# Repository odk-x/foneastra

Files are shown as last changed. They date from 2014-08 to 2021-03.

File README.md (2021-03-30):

# foneastra

This project is __*actively maintained*__

It defines the Foneastra controller board and software for communicating with it.

The developer [wiki](https://github.com/odk-x/tool-suite-X/wiki) (including release notes) and [issues tracker](https://github.com/odk-x/tool-suite-X/issues) are located under the [**ODK-X Tool Suite**](https://github.com/odk-x) project.

## How to contribute
If you’re new to ODK-X you can check out the documentation:
- [https://docs.odk-x.org](https://docs.odk-x.org)

Once you’re up and running, you can choose an issue to start working on from here: 
- [https://github.com/odk-x/tool-suite-X/issues](https://github.com/odk-x/tool-suite-X/issues)

Issues tagged as [good first issue](https://github.com/odk-x/tool-suite-X/issues?q=is%3Aissue+is%3Aopen+label%3A%22good+first+issue%22) should be a good place to start.

Pull requests are welcome, though please submit them against the development branch. We prefer verbose descriptions of the change you are submitting. If you are fixing a bug please provide steps to reproduce it or a link to a an issue that provides that information. If you are submitting a new feature please provide a description of the need or a link to a forum discussion about it. 

## Links for users
This document is aimed at helping developers and technical contributors. For information on how to get started as a user of ODK-X, see our [online documentation](https://docs.odk-x.org), or to learn more about the Open Data Kit project, visit [https://odk-x.org](https://odk-x.org).

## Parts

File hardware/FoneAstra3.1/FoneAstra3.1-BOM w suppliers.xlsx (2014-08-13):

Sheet: Sheet2
Part | Value | Device | Package | Description | Digikey/SFE Part | Additional notes
$$U3 | BT_RESET | TESTPOINT | TESTPOINT
$$U4 | PIO6 | TESTPOINT | TESTPOINT
$$U5 | PIO7 | TESTPOINT | TESTPOINT
$$U6 | GND | TESTPOINT | TESTPOINT
$$U9 | PIO4 | TESTPOINT | TESTPOINT
$$U10 | PIO3 | TESTPOINT | TESTPOINT
$$U11 | PIO5 | TESTPOINT | TESTPOINT
$$U15 | FT/OUT | TESTPOINT | TESTPOINT
$$U16 | GND | TESTPOINT | TESTPOINT
BAT1 | 3V | BATTERY | BATTCON_12MM_CURVED | Battery Holders | SFE: http://www.sparkfun.com/products/10592
BT_PWR | BT_PWR | TESTPOINT | TESTPOINT
C1 | 0.1uF | CAP0402-CAP | 0402-CAP | Capacitor | 445-3445-1-ND
C2 | 0.1uF | CAP0402-CAP | 0402-CAP | Capacitor | 445-3445-1-ND
C3 | 0.1uF | CAP0402-CAP | 0402-CAP | Capacitor | 445-3445-1-ND
C4 | 0.1uF | CAP0402-CAP | 0402-CAP | Capacitor | 445-3445-1-ND
C5 | 0.1uF | CAP0402-CAP | 0402-CAP | Capacitor | 445-3445-1-ND
C6 | 0.1uF | CAP0402-CAP | 0402-CAP | Capacitor | 445-3445-1-ND
C7 | 18pF | CAP0402-CAP | 0402-CAP | Capacitor | 445-1238-1-ND
C8 | 18pF | CAP0402-CAP | 0402-CAP | Capacitor | 445-1238-1-ND
C9 | 0.1uF | CAP0402-CAP | 0402-CAP | Capacitor | 445-3445-1-ND
C10 | 4.7uF | CAP0402-CAP | 0402-CAP | Capacitor | 445-7395-1-ND
C11 | 4.7uF | CAP0402-CAP | 0402-CAP | Capacitor | 445-7395-1-ND
C12 | 0.01uF | CAP0402-CAP | 0402-CAP | Capacitor | 399-4875-1-ND
C13 | 10uF | CAP_POL1206 | EIA3216 | Capacitor Polarized | 399-3687-1-ND
C14 | 0.1uF | CAP0402-CAP | 0402-CAP | Capacitor | 445-3445-1-ND
C15 | 10uF | CAP_POL1206 | EIA3216 | Capacitor Polarized | 399-3687-1-ND
JP1 | SPARKFUN_FIDUCIAL1.5X3 | SPARKFUN_FIDUCIAL1.5X3 | SPARKFUN_FIDUCIAL-1.5X3 | Fiducial Alignment Points
JP2 | ard_isp | PINHD-2X3 | 2X03 | PIN HEADER | 609-3218-ND
JP3 | STAND-OFFTIGHT | STAND-OFFTIGHT | STAND-OFF-TIGHT | #4 Stand Off
JP4 | IOPINS | PINHD-1X13M | 1X13M | PIN HEADER | 3M9402-ND + 3M9401-ND
JP5 | I2C | PINHD-1X4M | 1X04M | PIN HEADER | 3M9399-ND
JP6 | STAND-OFFTIGHT | STAND-OFFTIGHT | STAND-OFF-TIGHT | #4 Stand Off
JP7 | PWR | PINHD-1X5M | 1X05M | PIN HEADER | 3M9400-ND
JP8 | SPARKFUN_FIDUCIAL1.5X3 | SPARKFUN_FIDUCIAL1.5X3 | SPARKFUN_FIDUCIAL-1.5X3 | Fiducial Alignment Points
JP9 | STAND-OFFTIGHT | STAND-OFFTIGHT | STAND-OFF-TIGHT | #4 Stand Off
JP10 | flash-dbg | PINHD-2X6 | 2X06 | PIN HEADER | 609-3219-ND
JP11 | SPARKFUN_FIDUCIAL1.5X3 | SPARKFUN_FIDUCIAL1.5X3 | SPARKFUN_FIDUCIAL-1.5X3 | Fiducial Alignment Points
JP12 | Li-Ion Battery | SPARKFUN_M02JST-PTH-2 | SPARKFUN_JST-2-PTH | Header 2 | A100043-ND
JP13 | bt_isp | PINHD-2X3 | 2X03 | PIN HEADER | DO NOT assemble this
JP14 | SPARKFUN_FIDUCIAL1.5X3 | SPARKFUN_FIDUCIAL1.5X3 | SPARKFUN_FIDUCIAL-1.5X3 | Fiducial Alignment Points
JP15 | 1wb-hdr | M03JST-PTH | JST-3-PTH | Header 3 | 455-1720-ND
JP16 | 1wb-hdr | M03JST-PTH | JST-3-PTH | Header 3 | 455-1720-ND
JP17 | 1wb-hdr | M03JST-PTH | JST-3-PTH | Header 3 | 455-1720-ND
JP18 | 1wb-hdr | M03JST-PTH | JST-3-PTH | Header 3 | 455-1720-ND
LED1 | YELLOW | LED0603 | LED-0603 | LEDs | 751-1186-1-ND
LED2 | RED | LED0603 | LED-0603 | LEDs | 404-1000-1-ND
LED3 | Green | LED0603 | LED-0603 | LEDs | 404-1004-1-ND
LED4 | YELLOW | LED0603 | LED-0603 | LEDs | 751-1186-1-ND
LED5 | Blue | LED0603 | LED-0603 | LEDs | 160-1827-1-ND
LED6 | Green | LED0603 | LED-0603 | LEDs | 404-1004-1-ND
LED7 | Red | LED0603 | LED-0603 | LEDs | 404-1000-1-ND
PIO8 | PIO8 | TESTPOINT | TESTPOINT
Q1 | 8MHz | CRYSTALHC49S | HC49/S | CRYSTAL | CTX900-ND
R1 | 1k | RESISTOR0402-RES | 0402-RES | Resistor | P1.0KJCT-ND
R2 | 330 | RESISTOR0402-RES | 0402-RES | Resistor | P330JCT-ND
R3 | 330 | RESISTOR0402-RES | 0402-RES | Resistor | P330JCT-ND
R4 | 330 | RESISTOR0402-RES | 0402-RES | Resistor | P330JCT-ND
R5 | 330 | RESISTOR0402-RES | 0402-RES | Resistor | P330JCT-ND
R6 | 330 | RESISTOR0402-RES | 0402-RES | Resistor | P330JCT-ND
R7 | 220 | RESISTOR0402-RES | 0402-RES | Resistor | P220LCT-ND
R8 | 220 | RESISTOR0402-RES | 0402-RES | Resistor | P220LCT-ND
R9 | 1k | RESISTOR0402-RES | 0402-RES | Resistor | P1.0KJCT-ND
R10 | 1k | RESISTOR0402-RES | 0402-RES | Resistor | P1.0KJCT-ND
R11 | 5k | RESISTOR0402-RES | 0402-RES | Resistor | P5.1KJCT-ND
R12 | 10K | RESISTOR0402-RES | 0402-RES | Resistor | P10KJCT-ND
R13 | 100 | RESISTOR0402-RES | 0402-RES | Resistor | P100JCT-ND
R14 | 5k | RESISTOR0402-RES | 0402-RES | Resistor | P5.1KJCT-ND
R15 | 5k | RESISTOR0402-RES | 0402-RES | Resistor | P5.1KJCT-ND
R16 | 10K | RESISTOR0402-RES | 0402-RES | Resistor | P10KJCT-ND
R17 | 100k | RESISTOR0402-RES | 0402-RES | Resistor | P100KJCT-ND
R18 | 300k | RESISTOR0402-RES | 0402-RES | Resistor | P300KJCT-ND
R19 | 100k | RESISTOR0402-RES | 0402-RES | Resistor | P100KJCT-ND
R20 | 200k | RESISTOR0402-RES | 0402-RES | Resistor | P200KJCT-ND
R21 | 2K | RESISTOR0402-RES | 0402-RES | Resistor | P2.0KJCT-ND
R22 | 5k | RESISTOR0402-RES | 0402-RES | Resistor | P5.1KJCT-ND
S1 | switch | SPARKFUN_TAC_SWITCHPTH | SPARKFUN_TACTILE-PTH | Momentary Switch | EG1831-ND
S2 | E-SWITCH-EG1206 | E-SWITCH-EG1206 | EG1206 | Rt Angle slide switch | EG1916-ND
S3 | Reset | TAC_SWITCHSMD | TACTILE_SWITCH_SMD | Momentary Switch | SFE: https://www.sparkfun.com/products/8720
SG1 | BUZZERPTH | BUZZERPTH | BUZZER-12MM | Buzzer 12mm | 445-2525-1-ND
SJ1 |  | SOLDERJUMPERNC2 | SJ_2S-NOTRACE | Solder Jumper
SJ2 |  | SOLDERJUMPERNC2 | SJ_2S-NOTRACE | Solder Jumper
SS | SS | TESTPOINT | TESTPOINT
U7 | FSA4157AP6X | FSA4157AP6X | SC70-6 | IC Switch SPDT | FSA4157AP6XCT-ND
U8 | BLUETOOTH-RN42 | BLUETOOTH-RN41" | RN41 | RN42 Bluetooth SMD | SFE: https://www.sparkfun.com/products/10253
U12 | ATMEGA328 | ATMEGA168 | TQFP32-08 | ATMega328P Processor | ATMEGA328P-AU-ND
U13 | DS1340C-33 | DS1340C-33 | SO16L | I2C RTC | DS1340C-33#-ND
U17 | MCP73831 | MCP73831 | SOT23-5 | Microchip's MCP73831 | MCP73831T-2ACI/OTCT-ND
U18 | MIC5205 | V_REG_LDOSMD | SOT23-5 | Voltage Regulator LDO | 576-1259-1-ND
U19 | microSD | USD-SOCKETSMD | MICRO-SD-SOCKET-PP | microSD Socket | SFE: https://www.sparkfun.com/products/127
X1 | Micro USB | USB-MICROB | USB-MICROB | USB Connectors | 609-4053-1-ND
X2 | Micro USB | USB-MICROB | USB-MICROB | USB Connectors | 609-4053-1-ND
 | Other parts
 | micro USB AB charging cable | Cable | AE10424-ND | cable to charge phone via board | AE10424-ND
 | Li-ion battery | 2 pin JST terminated Li-ion battery |  |  | Example SFE part:https://www.sparkfun.com/products/8483 | Need to find a similar, cheaper battery
 | RTC backup battery | 12 mm coin cell |  |  | Example SFE part: https://www.sparkfun.com/products/337 | Same comment as above
 | Temperature probe | DS18b20 temp probe |  |  | Example SFE part: https://www.sparkfun.com/products/11050 | Chinese vendors on ebay sell similar probes of varying lengths for much cheaper
 | temp probe-board connector | 3-pin JST cable |  |  | Example SFE part: https://www.sparkfun.com/products/9915
 | Temperature sensor | DS18b20 temp sensor |  |  | Example SFE part: https://www.sparkfun.com/products/245 | In some use cases the bare temp sensor is soldered directly on to the board
 | microSD card | 4GB will be sufficient |  |  | Example amazon part: http://www.amazon.com/Kingston-microSDHC-Memory-SDC4-8GBET/dp/B00200K1TS
 | Enclosure

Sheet: Sheet1
Part Value Device Package Description MF MPN OC_FARNELL OC_NEWARK
$$U3 BT_RESET TESTPOINT TESTPOINT
$$U4 PIO6 TESTPOINT TESTPOINT
$$U5 PIO7 TESTPOINT TESTPOINT
$$U6 GND TESTPOINT TESTPOINT
$$U9 PIO4 TESTPOINT TESTPOINT
$$U10 PIO3 TESTPOINT TESTPOINT
$$U11 PIO5 TESTPOINT TESTPOINT
$$U15 FT/OUT TESTPOINT TESTPOINT
$$U16 GND TESTPOINT TESTPOINT
BAT1 3V BATTERY BATTCON_12MM_CURVED Battery Holders
BT_PWR BT_PWR TESTPOINT TESTPOINT
C1 0.1uF CAP0402-CAP 0402-CAP Capacitor
C2 0.1uF CAP0402-CAP 0402-CAP Capacitor
C3 0.1uF CAP0402-CAP 0402-CAP Capacitor
C4 0.1uF CAP0402-CAP 0402-CAP Capacitor
C5 0.1uF CAP0402-CAP 0402-CAP Capacitor
C6 0.1uF CAP0402-CAP 0402-CAP Capacitor
C7 18pF CAP0402-CAP 0402-CAP Capacitor
C8 18pF CAP0402-CAP 0402-CAP Capacitor
C9 0.1uF CAP0402-CAP 0402-CAP Capacitor
C10 4.7uF CAP0402-CAP 0402-CAP Capacitor
C11 4.7uF CAP0402-CAP 0402-CAP Capacitor
C12 0.01uF CAP0402-CAP 0402-CAP Capacitor
C13 10uF CAP_POL1206 EIA3216 Capacitor Polarized
C14 0.1uF CAP0402-CAP 0402-CAP Capacitor
C15 10uF CAP_POL1206 EIA3216 Capacitor Polarized
JP1 SPARKFUN_FIDUCIAL1.5X3 SPARKFUN_FIDUCIAL1.5X3 SPARKFUN_FIDUCIAL-1.5X3 Fiducial Alignment Points
JP2 ard_isp PINHD-2X3 2X03 PIN HEADER
JP3 STAND-OFFTIGHT STAND-OFFTIGHT STAND-OFF-TIGHT #4 Stand Off
JP4 IOPINS PINHD-1X13M 1X13M PIN HEADER
JP5 I2C PINHD-1X4M 1X04M PIN HEADER
JP6 STAND-OFFTIGHT STAND-OFFTIGHT STAND-OFF-TIGHT #4 Stand Off
JP7 PWR PINHD-1X5M 1X05M PIN HEADER
JP8 SPARKFUN_FIDUCIAL1.5X3 SPARKFUN_FIDUCIAL1.5X3 SPARKFUN_FIDUCIAL-1.5X3 Fiducial Alignment Points
JP9 STAND-OFFTIGHT STAND-OFFTIGHT STAND-OFF-TIGHT #4 Stand Off
JP10 flash-dbg PINHD-2X6 2X06 PIN HEADER
JP11 SPARKFUN_FIDUCIAL1.5X3 SPARKFUN_FIDUCIAL1.5X3 SPARKFUN_FIDUCIAL-1.5X3 Fiducial Alignment Points
JP12 Li-Ion Battery SPARKFUN_M02JST-PTH-2 SPARKFUN_JST-2-PTH Header 2
JP13 bt_isp PINHD-2X3 2X03 PIN HEADER
JP14 SPARKFUN_FIDUCIAL1.5X3 SPARKFUN_FIDUCIAL1.5X3 SPARKFUN_FIDUCIAL-1.5X3 Fiducial Alignment Points
JP15 1wb-hdr M03JST-PTH JST-3-PTH Header 3
JP16 1wb-hdr M03JST-PTH JST-3-PTH Header 3
JP17 1wb-hdr M03JST-PTH JST-3-PTH Header 3
JP18 1wb-hdr M03JST-PTH JST-3-PTH Header 3
LED1 YELLOW LED0603 LED-0603 LEDs
LED2 RED LED0603 LED-0603 LEDs
LED3 Green LED0603 LED-0603 LEDs
LED4 YELLOW LED0603 LED-0603 LEDs
LED5 Blue LED0603 LED-0603 LEDs
LED6 Green LED0603 LED-0603 LEDs
LED7 Red LED0603 LED-0603 LEDs
PIO8 PIO8 TESTPOINT TESTPOINT
Q1 8MHz CRYSTALHC49S HC49/S CRYSTAL 1667008 unknown
R1 1k RESISTOR0402-RES 0402-RES Resistor
R2 330 RESISTOR0402-RES 0402-RES Resistor
R3 330 RESISTOR0402-RES 0402-RES Resistor
R4 330 RESISTOR0402-RES 0402-RES Resistor
R5 330 RESISTOR0402-RES 0402-RES Resistor
R6 330 RESISTOR0402-RES 0402-RES Resistor
R7 220 RESISTOR0402-RES 0402-RES Resistor
R8 220 RESISTOR0402-RES 0402-RES Resistor
R9 1k RESISTOR0402-RES 0402-RES Resistor
R10 1k RESISTOR0402-RES 0402-RES Resistor
R11 5k RESISTOR0402-RES 0402-RES Resistor
R12 10K RESISTOR0402-RES 0402-RES Resistor
R13 100 RESISTOR0402-RES 0402-RES Resistor
R14 5k RESISTOR0402-RES 0402-RES Resistor
R15 5k RESISTOR0402-RES 0402-RES Resistor
R16 10K RESISTOR0402-RES 0402-RES Resistor
R17 100k RESISTOR0402-RES 0402-RES Resistor
R18 300k RESISTOR0402-RES 0402-RES Resistor
R19 100k RESISTOR0402-RES 0402-RES Resistor
R20 200k RESISTOR0402-RES 0402-RES Resistor
R21 2K RESISTOR0402-RES 0402-RES Resistor
R22 5k RESISTOR0402-RES 0402-RES Resistor
S1 switch SPARKFUN_TAC_SWITCHPTH SPARKFUN_TACTILE-PTH Momentary Switch
S2 E-SWITCH-EG1206 E-SWITCH-EG1206 EG1206
S3 Reset TAC_SWITCHSMD TACTILE_SWITCH_SMD Momentary Switch
SG1 BUZZERPTH BUZZERPTH BUZZER-12MM Buzzer 12mm
SJ1 SOLDERJUMPERNC2 SJ_2S-NOTRACE Solder Jumper
SJ2 SOLDERJUMPERNC2 SJ_2S-NOTRACE Solder Jumper
SS SS TESTPOINT TESTPOINT
U7 FSA4157AP6X FSA4157AP6X SC70-6
U8 BLUETOOTH-RN42 BLUETOOTH-RN41" RN41
U12 ATMEGA328 ATMEGA168 TQFP32-08
U13 DS1340C-33 DS1340C-33 SO16L
U17 MCP73831 MCP73831 SOT23-5 Microchip's MCP73831
U18 MIC5205 V_REG_LDOSMD SOT23-5 Voltage Regulator LDO
U19 microSD USD-SOCKETSMD MICRO-SD-SOCKET-PP microSD Socket
X1 Micro USB USB-MICROB USB-MICROB USB Connectors
X2 Micro USB USB-MICROB USB-MICROB USB Connectors

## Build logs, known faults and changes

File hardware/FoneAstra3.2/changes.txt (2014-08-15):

11/23/13. v3.2 Schematic changes (not completed in the layout) 

- BT_PWR is pulled high
- Disconnected BT_RESET from ATMega.
- Added DIP switch S4. D5, BUZZER, BATT_LVL, WALL, DTR are on DIP switch.
- added 2 more 1WB sockets
- Red LED7 is connected to D4
- Green LED3 is connected to D5_DP (& to D5 thru S4).

11/23/13 TODOs for v3.2
- replace MCP73831 with ADP5062. Need to make sure that battery charging indicator LED1 works correctly.
- connect ADP5062 to ATMega's I2C bus
- replace the 2mm pitch connection headers with 2.54mm (0.1") connection headers.
- find a preassembled battery alternative.
- temperature probe needs to be preassembed.
- switch to PTH micro USB sockets
- complete the PCB layout to incorporate all schematic changes.  
- update board version number to 3.2 in the layout slikscreen. 

12/11/2012. v3.1
- upgraded to EAGLE version 6.3.0
- changed silkscreen text to reflect version 3.1 
- moved RTC battery holder so that it doesn't overlap with the I2C & PWR headers
- rerouted some tracks/vias due to the change above
- renamed all project files from 3.0_v4..... to 3.1

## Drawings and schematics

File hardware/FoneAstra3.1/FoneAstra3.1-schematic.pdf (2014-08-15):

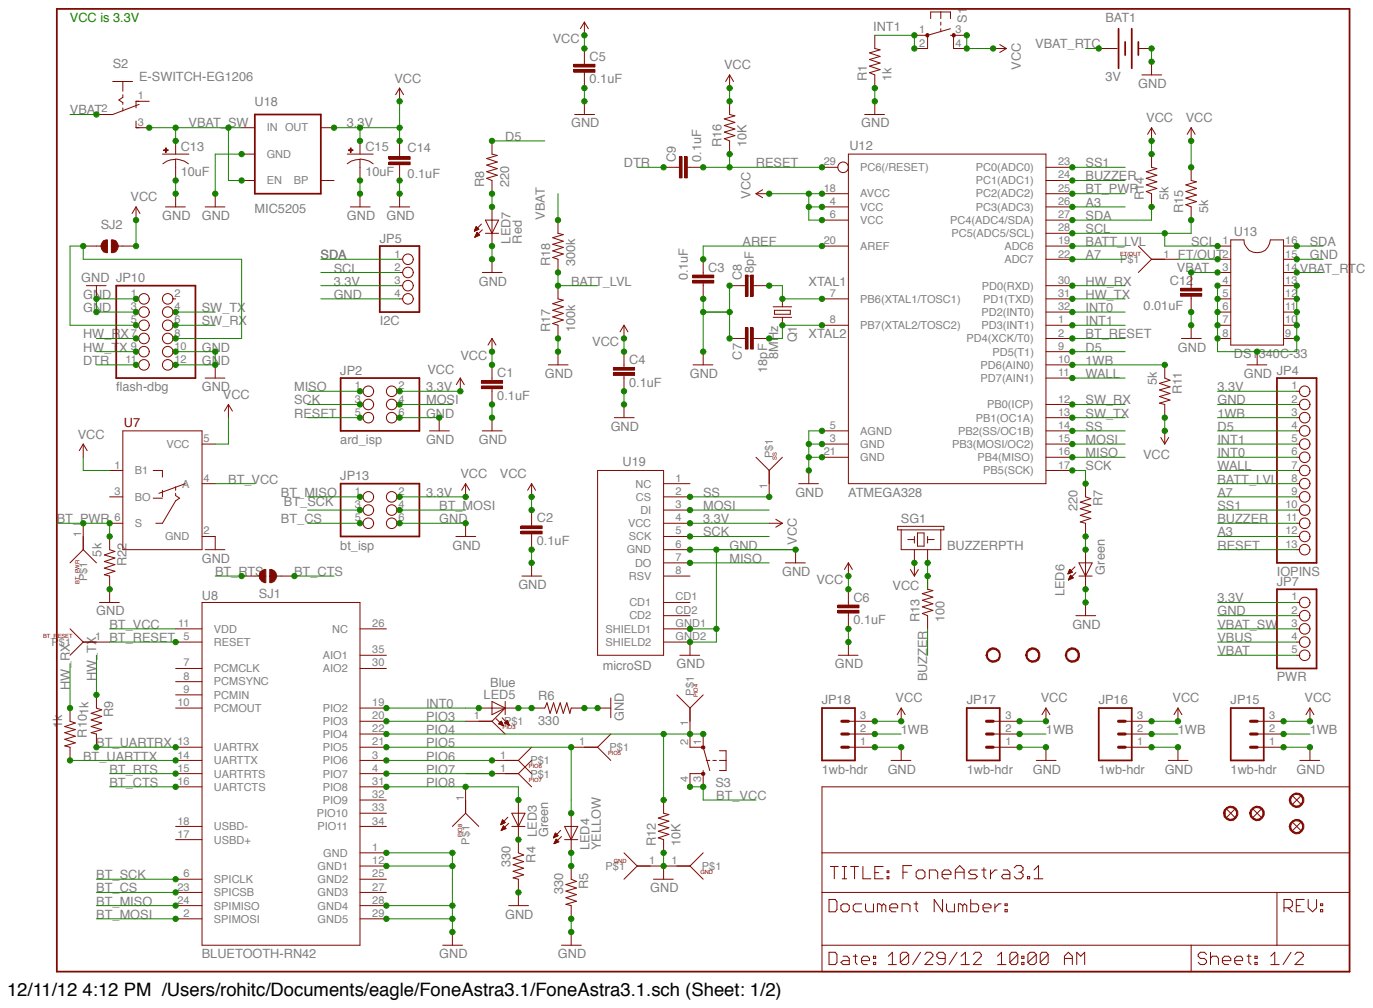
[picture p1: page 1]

12/11/12 4:12 PM /Users/rohitc/Documents/eagle/FoneAstra3.1/FoneAstra3.1.sch (Sheet: 1/2)

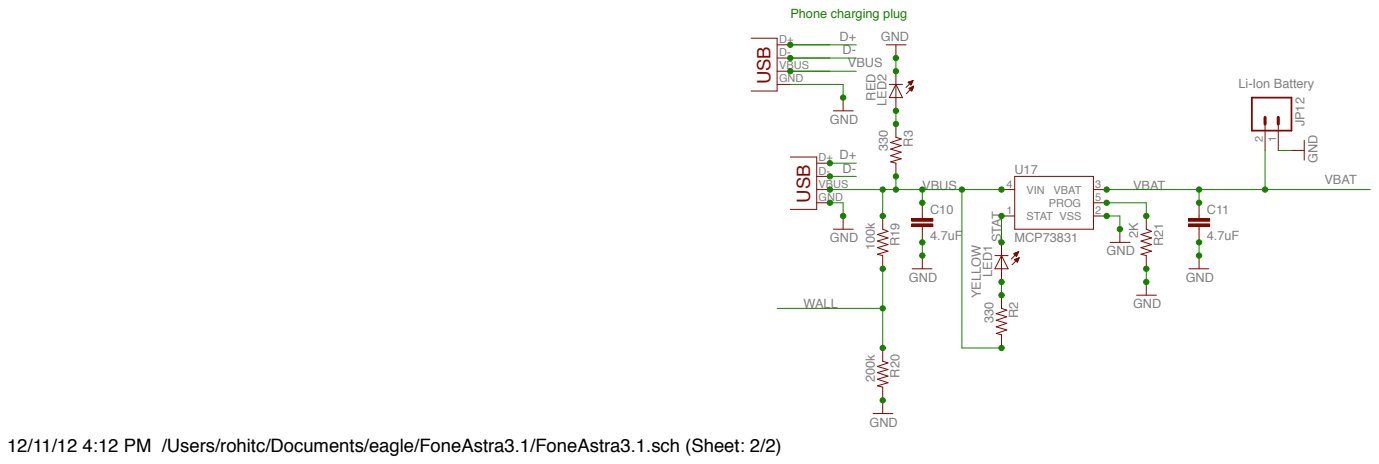
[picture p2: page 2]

12/11/12 4:12 PM /Users/rohitc/Documents/eagle/FoneAstra3.1/FoneAstra3.1.sch (Sheet: 2/2)

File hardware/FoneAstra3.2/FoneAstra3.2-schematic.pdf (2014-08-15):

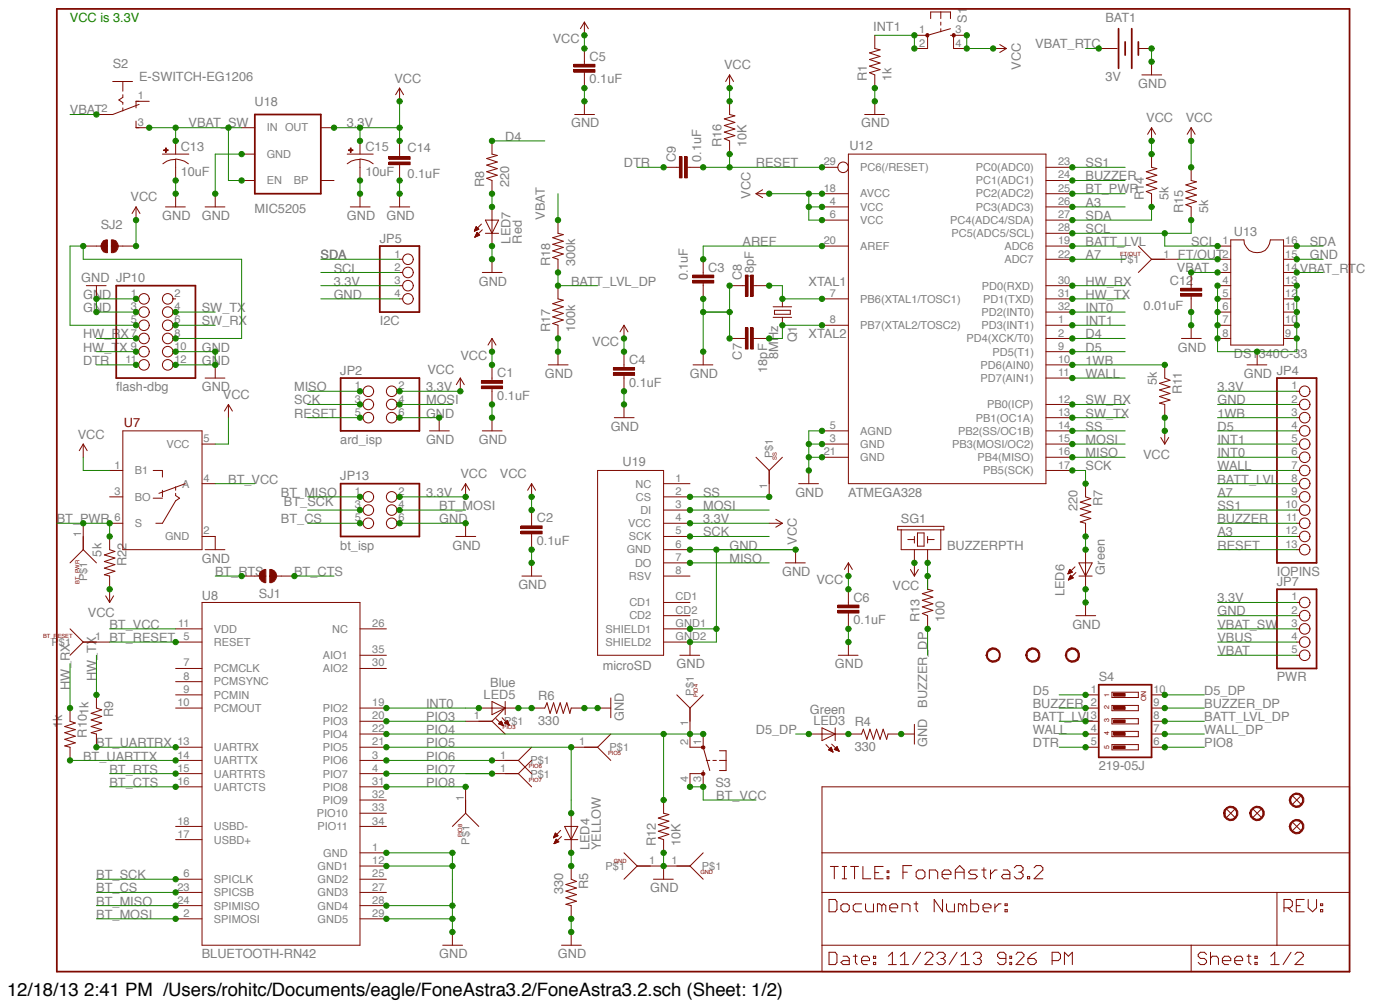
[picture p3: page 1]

12/18/13 2:41 PM /Users/rohitc/Documents/eagle/FoneAstra3.2/FoneAstra3.2.sch (Sheet: 1/2)

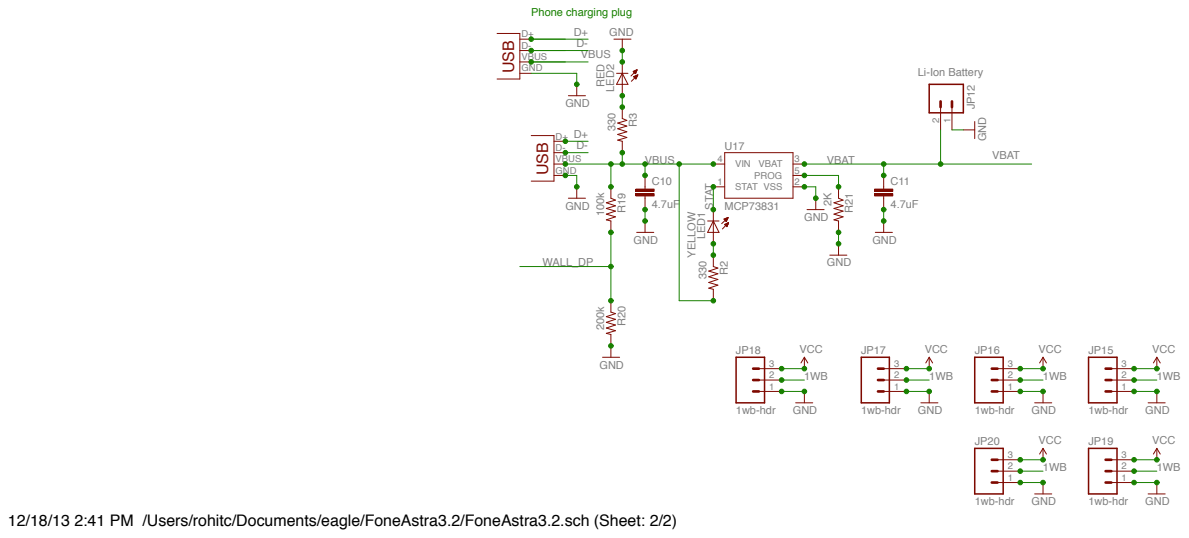
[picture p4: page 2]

12/18/13 2:41 PM /Users/rohitc/Documents/eagle/FoneAstra3.2/FoneAstra3.2.sch (Sheet: 2/2)

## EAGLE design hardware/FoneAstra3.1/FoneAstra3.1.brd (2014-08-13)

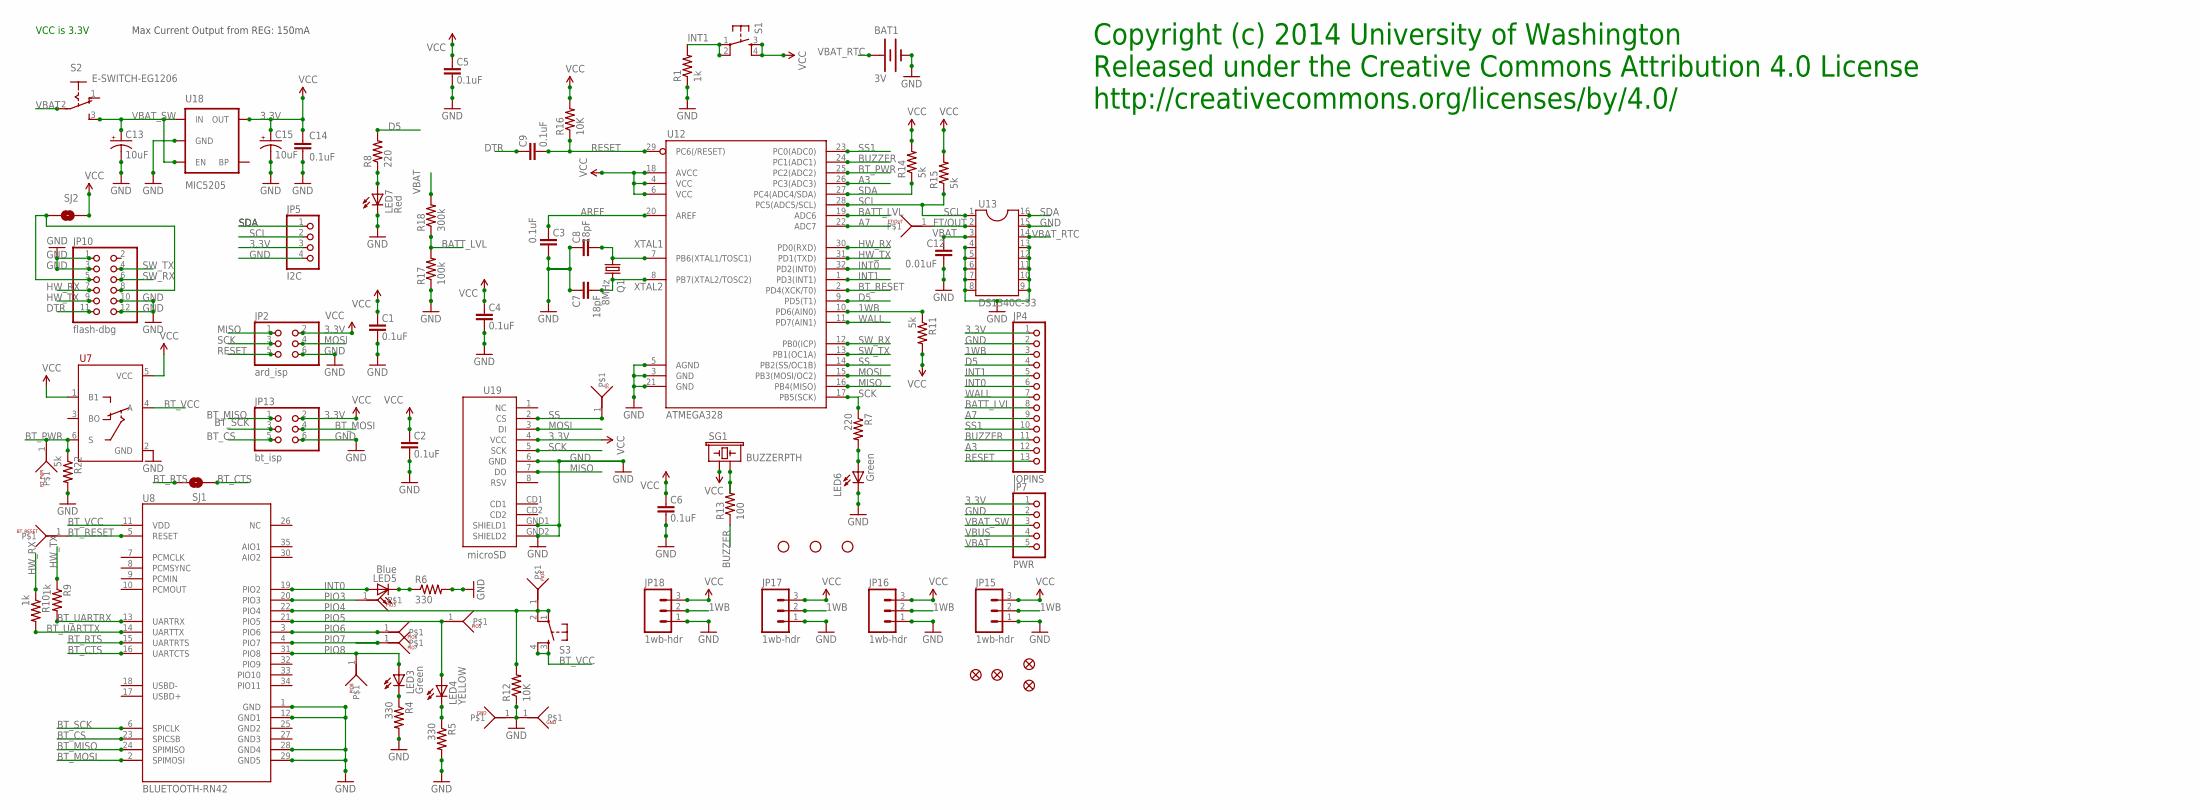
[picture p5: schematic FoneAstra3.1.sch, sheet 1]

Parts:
$$U3: BT_RESET; TESTPOINT
$$U4: PIO6; TESTPOINT
$$U5: PIO7; TESTPOINT
$$U6, $$U16: GND; TESTPOINT
$$U9: PIO4; TESTPOINT
$$U10: PIO3; TESTPOINT
$$U11: PIO5; TESTPOINT
$$U15: FT/OUT; TESTPOINT
BAT1: 3V; BATTCON_12MM_CURVED
BT_PWR: BT_PWR; TESTPOINT
C1, C2, C3, C4, C5, C6, C9, C14: 0.1uF; 0402-CAP
C7, C8: 18pF; 0402-CAP
C12: 0.01uF; 0402-CAP
C13, C15: 10uF; EIA3216
JP1, JP8, JP11, JP14: SPARKFUN_FIDUCIAL1.5X3; SPARKFUN_FIDUCIAL-1.5X3
JP2: ard_isp; 2X03
JP3, JP6, JP9: STAND-OFFTIGHT; STAND-OFF-TIGHT
JP4: IOPINS; 1X13M
JP5: I2C; 1X04M
JP7: PWR; 1X05M
JP10: flash-dbg; 2X06
JP13: bt_isp; 2X03
JP15, JP16, JP17, JP18: 1wb-hdr; JST-3-PTH
LED3, LED6: Green; LED-0603
LED4: YELLOW; LED-0603
LED5: Blue; LED-0603
LED7: Red; LED-0603
PIO8: PIO8; TESTPOINT
Q1: 8MHz; HC49/S
R1, R9, R10: 1k; 0402-RES
R4, R5, R6: 330; 0402-RES
R7, R8: 220; 0402-RES
R11, R14, R15, R22: 5k; 0402-RES
R12, R16: 10K; 0402-RES
R13: 100; 0402-RES
R17: 100k; 0402-RES
R18: 300k; 0402-RES
S1: switch; SPARKFUN_TACTILE-PTH
S2: E-SWITCH-EG1206; EG1206
S3: Reset; TACTILE_SWITCH_SMD
SG1: BUZZERPTH; BUZZER-12MM
SJ1, SJ2: SOLDERJUMPERNC2; SJ_2S-NOTRACE
SS: SS; TESTPOINT
U7: FSA4157AP6X; SC70-6
U8: BLUETOOTH-RN42; RN41
U12: ATMEGA328; TQFP32-08
U13: DS1340C-33; SO16L
U18: MIC5205; SOT23-5
U19: microSD; MICRO-SD-SOCKET-PP

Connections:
1WB: JP4.3, JP15.2, JP16.2, JP17.2, JP18.2, R11.1, U12.10 (PD6(AIN0))
3.3V: C1.2, C2.2, C4.2, C5.2, C6.2, C14.1, C15.A (+), JP2.2, JP4.1, JP5.3, JP7.1, JP13.2, JP15.3, JP16.3, JP17.3, JP18.3, R11.2, R14.2, R15.2, R16.2, S1.3, S1.4, SG1.+ (1), SJ2.1, U7.1 (B1), U7.5 (VCC), U12.4 (VCC), U12.6 (VCC), U12.18 (AVCC), U18.5 (OUT), U19.4 (VCC)
A3: JP4.12, U12.26 (PC3(ADC3))
A7: JP4.9, U12.22 (ADC7)
AREF: C3.2, U12.20 (AREF)
BATT_LVL: JP4.8, R17.2, R18.1, U12.19 (ADC6)
BT_CS: JP13.5, U8.23 (SPICSB)
BT_CTS: SJ1.1, U8.16 (UARTCTS)
BT_MISO: JP13.1, U8.24 (SPIMISO)
BT_MOSI: JP13.4, U8.2 (SPIMOSI)
BT_PWR: BT_PWR.1, R22.1, U7.6 (S), U12.25 (PC2(ADC2))
BT_RESET: $$U3.1, U8.5 (RESET), U12.2 (PD4(XCK/T0))
BT_RTS: SJ1.2, U8.15 (UARTRTS)
BT_SCK: JP13.3, U8.6 (SPICLK)
BT_UARTRX: R9.2, U8.13 (UARTRX)
BT_UARTTX: R10.2, U8.14 (UARTTX)
BT_VCC: S3.3, S3.4, U7.4 (A), U8.11 (VDD)
BUZZER: JP4.11, R13.1, U12.24 (PC1(ADC1))
D1: LED4.C, R5.1
D4: LED5.C, R6.1
D5: JP4.4, R8.2, U12.9 (PD5(T1))
DTR: C9.2, JP10.11
FT/OUT: $$U15.1, U13.2
GND: $$U6.1, $$U16.1, BAT1.GND (-), C1.1, C2.1, C3.1, C4.1, C5.1, C6.1, C7.2, C8.2, C12.1, C13.C (-), C14.2, C15.C (-), JP2.6, JP4.2, JP5.4, JP7.2, JP10.1, JP10.3, JP10.10, JP10.12, JP13.6, JP15.1, JP16.1, JP17.1, JP18.1, LED6.C, LED7.C, R1.1, R4.2, R5.2, R6.2, R12.1, R17.1, R22.2, U7.2 (GND), U8.1 (GND), U8.12 (GND1), U8.28 (GND4), U8.29 (GND5), U12.3 (GND), U12.5 (AGND), U12.21 (GND), U13.4, U13.5, U13.6, U13.7, U13.8, U13.9, U13.10, U13.11, U13.12, U13.13, U13.15, U18.2 (GND), U19.6 (GND), U19.GND1 (SHIELD1), U19.GND2 (SHIELD2); also elsewhere on the board
HW_RX: JP10.7, R10.1, U12.30 (PD0(RXD))
HW_TX: JP10.9, R9.1, U12.31 (PD1(TXD))
INT0: JP4.6, LED5.A, U8.19 (PIO2), U12.32 (PD2(INT0))
INT1: JP4.5, R1.2, S1.1, S1.2, U12.1 (PD3(INT1))
MISO: JP2.1, U12.16 (PB4(MISO)), U19.7 (DO)
MOSI: JP2.4, U12.15 (PB3(MOSI/OC2)), U19.3 (DI)
unnamed: R13.2, SG1.- (2)
unnamed: JP10.5, JP10.8, SJ2.2
unnamed: LED3.C, R4.1
unnamed: LED6.A, R7.2
unnamed: LED7.A, R8.1
PIO3: $$U10.1, U8.20 (PIO3)
PIO4: $$U9.1, R12.2, S3.1, S3.2, U8.22 (PIO4)
PIO5: $$U11.1, LED4.A, U8.21 (PIO5)
PIO6: $$U4.1, U8.3 (PIO6)
PIO7: $$U5.1, U8.4 (PIO7)
PIO8: LED3.A, PIO8.1, U8.31 (PIO8)
RESET: C9.1, JP2.5, JP4.13, R16.1, U12.29 (PC6(/RESET))
SCK: JP2.3, R7.1, U12.17 (PB5(SCK)), U19.5 (SCK)
SCL: JP5.2, R15.1, U12.28 (PC5(ADC5/SCL)), U13.1
SDA: JP5.1, R14.1, U12.27 (PC4(ADC4/SDA)), U13.16
SS: SS.1, U12.14 (PB2(SS/OC1B)), U19.2 (CS)
SS1: JP4.10, U12.23 (PC0(ADC0))
SW_RX: JP10.6, U12.12 (PB0(ICP))
SW_TX: JP10.4, U12.13 (PB1(OC1A))
VBAT: C12.2, JP7.5, R18.2, S2.2, U13.3; also elsewhere on the board
VBAT_RTC: BAT1.PWR@1 (+), U13.14
VBAT_SW: C13.A (+), JP7.3, S2.3 (S), U18.1 (IN), U18.3 (EN)
VBUS: JP7.4; also elsewhere on the board
WALL: JP4.7, U12.11 (PD7(AIN1)); also elsewhere on the board
XTAL1: C8.1, Q1.1, U12.7 (PB6(XTAL1/TOSC1))
XTAL2: C7.1, Q1.2, U12.8 (PB7(XTAL2/TOSC2))

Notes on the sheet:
Max Current Output from REG: 150mA
VCC is 3.3V
Copyright (c) 2014 University of Washington Released under the Creative Commons Attribution 4.0 License http://creativecommons.org/licenses/by/4.0/

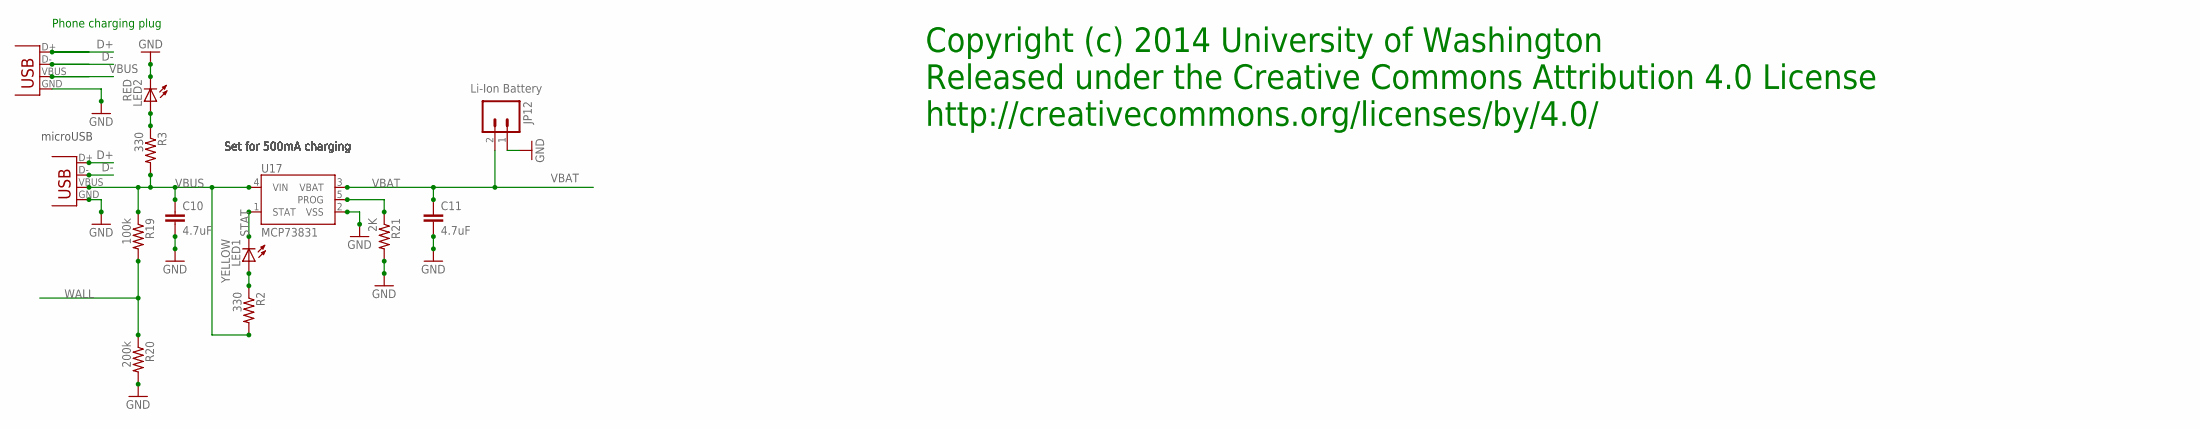
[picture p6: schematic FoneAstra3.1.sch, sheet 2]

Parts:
C10, C11: 4.7uF; 0402-CAP
JP12: Li-Ion Battery; SPARKFUN_JST-2-PTH
LED1: YELLOW; LED-0603
LED2: RED; LED-0603
R2, R3: 330; 0402-RES
R19: 100k; 0402-RES
R20: 200k; 0402-RES
R21: 2K; 0402-RES
U17: MCP73831; SOT23-5
X1, X2: Micro USB; USB-MICROB

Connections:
D+: X1.D+, X2.D+
D-: X1.D-, X2.D-
GND: C10.2, C11.2, JP12.1, LED2.C, R20.2, R21.2, U17.2 (VSS), X1.GND, X2.GND; also elsewhere on the board
unnamed: LED2.A, R3.1
unnamed: LED1.A, R2.1
PROG: R21.1, U17.5 (PROG)
STAT: LED1.C, U17.1 (STAT)
VBAT: C11.1, JP12.2, U17.3 (VBAT); also elsewhere on the board
VBUS: C10.1, R2.2, R3.2, R19.1, U17.4 (VIN), X1.VBUS, X2.VBUS; also elsewhere on the board
WALL: R19.2, R20.1; also elsewhere on the board

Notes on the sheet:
Set for 500mA charging
microUSB
Phone charging plug
Copyright (c) 2014 University of Washington Released under the Creative Commons Attribution 4.0 License http://creativecommons.org/licenses/by/4.0/

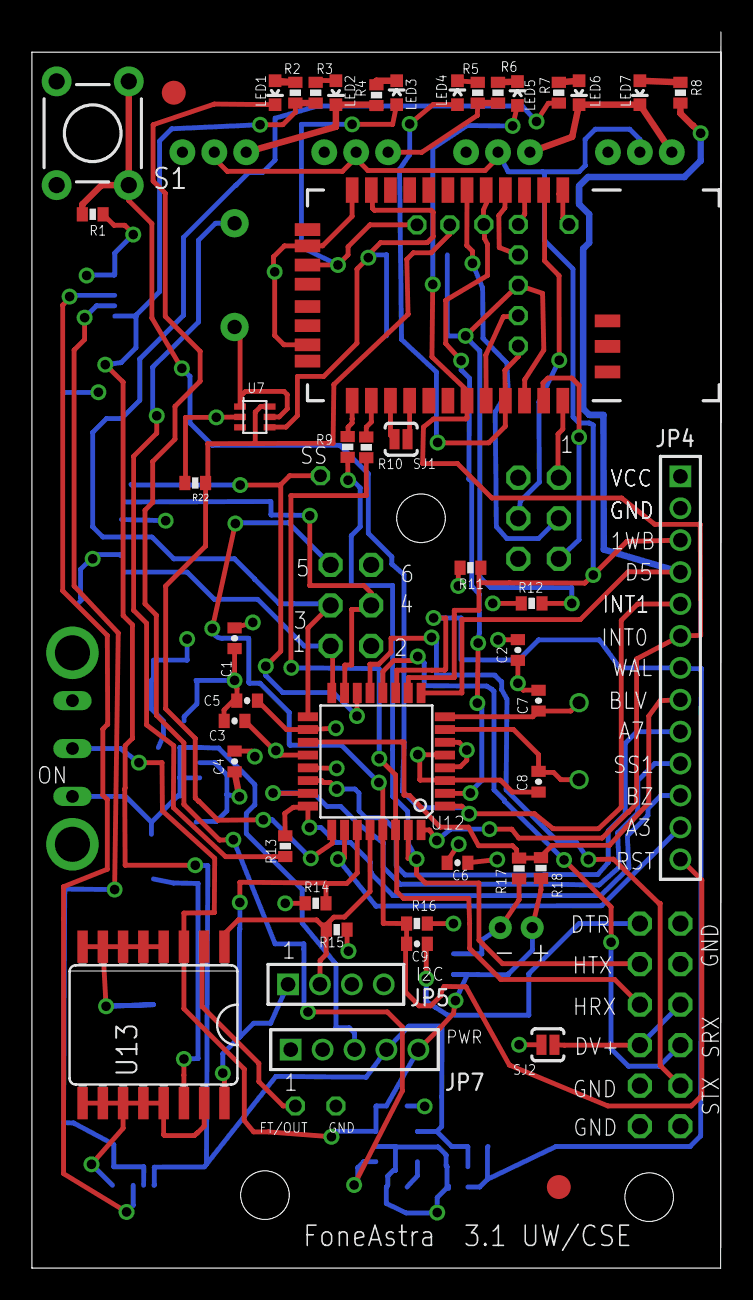
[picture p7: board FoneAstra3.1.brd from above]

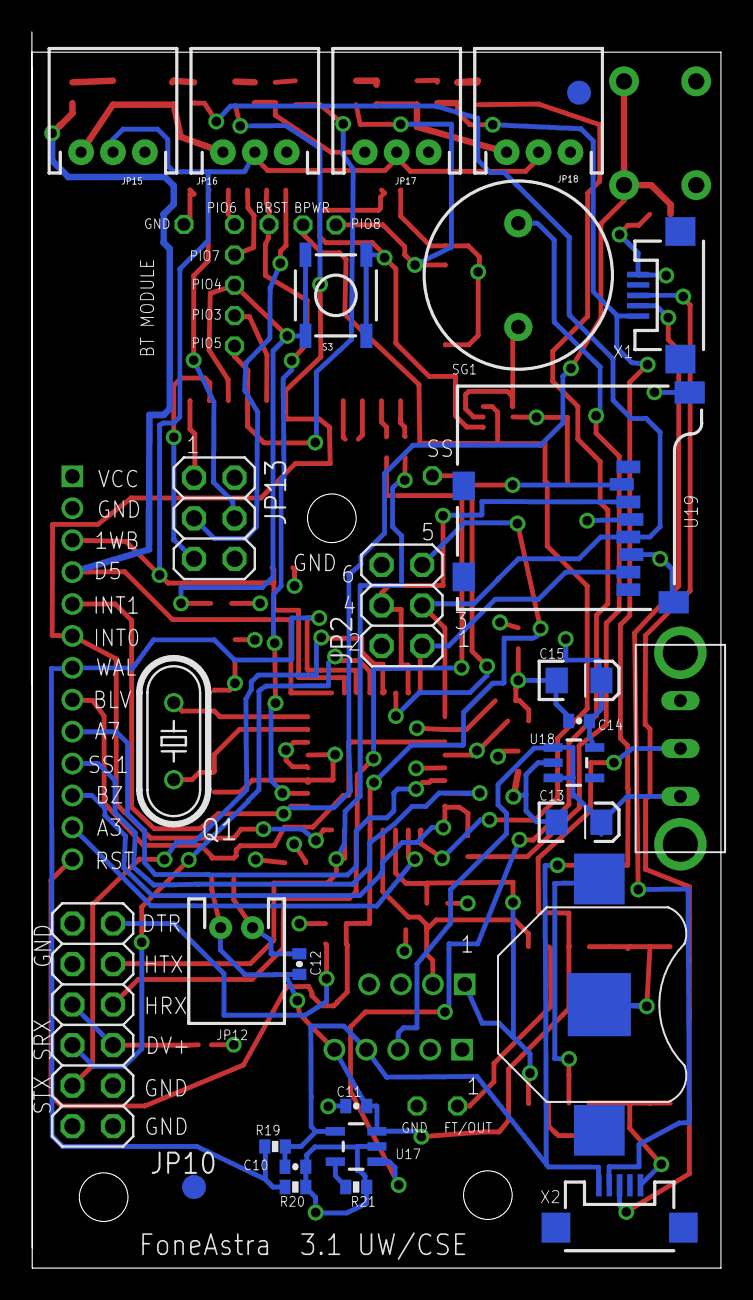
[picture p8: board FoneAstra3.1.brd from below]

Board: 4 copper layers, 43.2 x 77.5 mm, 91 parts (29 on the bottom side), 62 nets.

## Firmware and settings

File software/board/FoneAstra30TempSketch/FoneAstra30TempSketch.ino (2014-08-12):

/*
 * Copyright (C) 2014 University of Washington
 *
 * Licensed under the Apache License, Version 2.0 (the "License"); you may not
 * use this file except in compliance with the License. You may obtain a copy of
 * the License at
 *
 * http://www.apache.org/licenses/LICENSE-2.0
 *
 * Unless required by applicable law or agreed to in writing, software
 * distributed under the License is distributed on an "AS IS" BASIS, WITHOUT
 * WARRANTIES OR CONDITIONS OF ANY KIND, either express or implied. See the
 * License for the specific language governing permissions and limitations under
 * the License.
 */

#include <OneWire.h>
//#include <SoftwareSerial.h>

#include "foneastrapins.h"

const uint8_t SYNC_BYTE = 0xaa; //10101010
const int NO_OF_SYNC_BYTES = 10;
const int PAYLOAD_SIZE = 256;
const int MAX = NO_OF_SYNC_BYTES + PAYLOAD_SIZE;

//payload structure of MT_SINGLE_READING is: 
//MSG_TYPE (1 byte), SEQ_NO (2 bytes), MSG_DATA (PAYLOAD_SIZE - 4 bytes) CRC (1 byte)

//XXX should be using the same payload structure, MSG_DATA_BEGIN_INDEX for both MT_SINGLE_READING & 
//MT_BULK_TRANSFER. But not doing that just yet!

const int PAYLOAD_BEGIN_INDEX = NO_OF_SYNC_BYTES;
const int MSG_DATA_BEGIN_INDEX = PAYLOAD_BEGIN_INDEX + 3;

//message types
const int MT_SINGLE_READING = 1; //1 temp reading per msg
//const int MT_BULK_TRANSFER = 2; //variable size. will have more metadata
//const int MT_COLLECT_ALL = 3;
//const int MT_COLLECT_ONE = 4;
//const int MT_DELETE_ALL = 5;
//const int MT_DELETE_ONE = 6;

const int SAMPLING_INTERVAL = 1000; //millisecs.

// 1-wire sensors are connected on ONEWIRE_PIN
OneWire  owTempSensor(ONEWIRE_PIN); 
//SoftwareSerial dbgSerial(SW_UART_RX_PIN, SW_UART_TX_PIN); // RX, TX

uint8_t dataArray[MAX];
uint16_t counter = 0;
uint8_t msgType = MT_SINGLE_READING;
uint8_t present = 0;
uint8_t owbData[12];
uint8_t addr[8];

void setup(void) {
	//set up the HW UART to communicate with the BT module
	Serial.begin(115200);
//	Serial.begin(38400);
//	Serial.begin(57600);
	// set up the sofrware UART. haven't gotten this to work at 115200
	//but 57600 is just fine for the debug console.
//	dbgSerial.begin(57600);  

	//this tells us when a BT device connects to foneastra
	pinMode(INT0_PIN, INPUT);

	//this tells us when the tactile switch is pressed
	pinMode(INT1_PIN, INPUT);

	//this tells us the battery level
	pinMode(BATT_LVL_PIN, INPUT);

	//this tells us whether or not wall power is present
	pinMode(WALL_PIN,INPUT);

	//this controls power to the BT module
	pinMode(BT_PWR_PIN,OUTPUT);
	
	//LED pins as output
	pinMode(RED_LED_PIN,OUTPUT);
	pinMode(GREEN_LED_PIN,OUTPUT);
	
	digitalWrite(GREEN_LED_PIN,HIGH);

//	showBattLvl();		
	
	memset(dataArray,0,sizeof(dataArray));
	for(int i = 0;i < PAYLOAD_BEGIN_INDEX;i++) {
		dataArray[i]=SYNC_BYTE;
	}

	findSensorAndTurnBTOn();
}

//void showBattLvl() {
//	//FA has a 4.2V Li-Ion battery. determined the hard coded values below based on experiments. 
//	
//	//read 10 bit ADC
//	uint16_t battLvl = analogRead(BATT_LVL_PIN);
//	int8_t blnkCnt = 0;
//	
//	if(battLvl >= 310) {
//		blnkCnt = 5;
//	}
//	else if((battLvl >= 290) & (battLvl < 310) ) {
//		blnkCnt = 4;
//	}
//	else if((battLvl >= 270) & (battLvl < 290)) {
//		blnkCnt = 3;
//	}
//	else if(battLvl < 270) {
//		blnkCnt = 1;
//	}
//	
////	dbgSerial.print(F("Batt Lvl: "));dbgSerial.print(battLvl);dbgSerial.print(F(" Blink cnt: "));dbgSerial.print(blnkCnt);
////	dbgSerial.println();
//	
//	for(int8_t i = 0; i< blnkCnt;i++) {
//		digitalWrite(RED_LED_PIN,HIGH);
//		delay(500);
//		digitalWrite(RED_LED_PIN,LOW);
//		delay(500);
//	}
//	
//}

void loop(void) {

	byte i; 
	float celsius;

	if(present && (digitalRead(INT0_PIN) == HIGH)) {

		unsigned long startreading = millis();

		owTempSensor.reset();
		owTempSensor.select(addr);
		owTempSensor.write(0x44,1);         // start conversion, with parasite power on at the end

		byte status = owTempSensor.read();

		while (!status) {
			delay(10);
			status = owTempSensor.read();
		}

		owTempSensor.reset();
		owTempSensor.select(addr);    
		owTempSensor.write(0xBE);         // Read Scratchpad

		for ( i = 0; i < 9; i++) {           // we need 9 bytes
			owbData[i] = owTempSensor.read();
		}

		unsigned long sensorReadTime = millis() - startreading;

		// convert the data to actual temperature
		unsigned int raw = (owbData[1] << 8) | owbData[0];

		celsius = (float)raw / 16.0;

		//send data over BT if there is an active connection
		if(digitalRead(INT0_PIN) == HIGH)  {
			
			++counter;

			dataArray[PAYLOAD_BEGIN_INDEX] = msgType;
			memcpy(&dataArray[PAYLOAD_BEGIN_INDEX + 1], &counter,sizeof(counter));
			dataArray[MSG_DATA_BEGIN_INDEX] = owbData[0];
			dataArray[MSG_DATA_BEGIN_INDEX+1] = owbData[1];
			uint8_t crc = getCRC(dataArray);
			dataArray[MAX -1] = crc;					

			Serial.write(dataArray,sizeof(dataArray));		
			Serial.flush();

//			dbgSerial.print("pkt no: "); dbgSerial.print(counter);
//			dbgSerial.print(" CRC: ");dbgSerial.print(crc);
//			dbgSerial.print(" hi : ");dbgSerial.print(owbData[1]);dbgSerial.print("lo : ");dbgSerial.print(owbData[0]);
//			dbgSerial.print(" raw: "); dbgSerial.print(raw,DEC);
//			dbgSerial.print(" decoded: ");dbgSerial.print(celsius);dbgSerial.print(" C ");
//			dbgSerial.println();
		}

		delay(SAMPLING_INTERVAL - sensorReadTime);
	}

	else {
		if(!present) 
			findSensorAndTurnBTOn();

		delay(SAMPLING_INTERVAL);   
	}
}

void findSensorAndTurnBTOn(void) {
	//find the temp sensor
	present = 0;
	present = owTempSensor.search(addr);

	if (OneWire::crc8(addr, 7) != addr[7]) {
//		dbgSerial.println("owTempSensor->CRC not valid ");
		present = 0;
	}

	if (addr[0] != 0x28) {
//		dbgSerial.println("owTempSensor-> not a DS18b20 device ");
		present = 0;
	}

	if(!present) {
//		dbgSerial.println("ERROR! temp sensor not found ");    
		digitalWrite(RED_LED_PIN, HIGH);
		digitalWrite(BT_PWR_PIN, LOW);
	}
	else {
//		dbgSerial.println("found temp sensor ");    
		digitalWrite(RED_LED_PIN, LOW);
		digitalWrite(BT_PWR_PIN, HIGH);
	}        
}

uint8_t getCRC(uint8_t *buff) {
	uint8_t crc = 0;

	for(int i = PAYLOAD_BEGIN_INDEX; i< MAX-1; i++) {
		crc ^= buff[i]; 
	}
	return crc;
}

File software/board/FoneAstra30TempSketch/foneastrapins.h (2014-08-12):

/*
 * Copyright (C) 2014 University of Washington
 *
 * Licensed under the Apache License, Version 2.0 (the "License"); you may not
 * use this file except in compliance with the License. You may obtain a copy of
 * the License at
 *
 * http://www.apache.org/licenses/LICENSE-2.0
 *
 * Unless required by applicable law or agreed to in writing, software
 * distributed under the License is distributed on an "AS IS" BASIS, WITHOUT
 * WARRANTIES OR CONDITIONS OF ANY KIND, either express or implied. See the
 * License for the specific language governing permissions and limitations under
 * the License.
 */

#ifndef __FONEASTRA_PINS_H__
#define __FONEASTRA_PINS_H__

/*
this file maps pins on the FoneAstra board to an AtMega328 based Arduino (Uno, mini, pro mini)
Arduino-ATMega pin mapping available at:
http://www.arduino.cc/en/Hacking/PinMapping168
 */

//SS1_PIN

//BUZZER_PIN: an audio buzzer is connected to this pin. 

//BT_PWR_PIN: this controls power to the BT module. driving this high turns the module on, low is off.

//A3_PIN

//I2C SDA, SCL pins already defined in Contents/Resources/Java/hardware/arduino/variants/standard/pins_arduino.h 

//BATT_LVL_PIN: this is a voltage divider and used for an approximate measure of battery charge

//A7_PIN

//INT0_PIN: goes high when a BT device connects (blue LED goes on), low otherwise. 

//INT1_PIN: connected to a tactile switch. Goes high when the switch is pressed.

//BT_RESET_PIN: this pin can reset the BT module.  

//D5_PIN

//ONEWIRE_PIN: 1-wire sensors are connected to this pin. The temperature sensor used in HMB & VAX apps is a 1wb sensor.  

//WALL_PIN: high when a usb charger is connected to the board, low otherwise. 
//
//the BT module is connected to ATMega's h/w UART, so for apps that use the BT module, we have a software UART 
//for the serial console. foneastra's UARTs are accessible on a 2x6 male header. The pins on the inner row are the
//HW UART & used for downloading code on the board. The pins on the outer row are the SW UART & can be used with 
//the serial console if HW UART is being used for BT communications
//
//SW_UART_RX: the rx pin of the s/w uart 

//SW_UART_TX: the tx pin of the h/w uart. 

//SPI SS, MOSI, MISO, SCK pns already defined in pins_arduino.h

#define SS1_PIN A0
#define BUZZER_PIN A1
#define BT_PWR_PIN A2
#define A3_PIN A3

//I2C pins. Already defined in Contents/Resources/Java/hardware/arduino/variants/standard/pins_arduino.h
//#define SDA A4
//#define SCL A5

#define BATT_LVL_PIN A6
#define A7_PIN A7

#define HW_UART_RX_PIN 0
#define HW_UART_TX_PIN 1
#define INT0_PIN 2
#define INT1_PIN 3
#define BT_RESET_PIN 4
#define D5_PIN 5
#define ONEWIRE_PIN 6
#define WALL_PIN 7
#define SW_UART_RX_PIN 8
#define SW_UART_TX_PIN 9

#define RED_LED_PIN D5_PIN
#define GREEN_LED_PIN SCK

//SPI pins. Already defined in Contents/Resources/Java/hardware/arduino/variants/standard/pins_arduino.h
//#define SS 10
//#define MOSI 11
//#define MISO 12
//#define SCK 13

#endif

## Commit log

2014-08-12 Initial checkin for android code
    [proguard.cfg]
2014-08-13 Sensor demo with androidcommon version rev 121 US Army Preparedness Demo 2014
2014-08-13 The EAGLE projects for FoneAstra 3.1 and 3.2
    [FoneAstra3.1-BOM w suppliers.xlsx, FoneAstra3.1.brd, FoneAstra3.1.sch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]
2014-08-14 STL files for the enclosure
2014-08-15 added pdfs for schematics, updated v3.2 changes.txt
2014-11-05 Change to make the temperature sensor demo work
2016-08-10 port projects to Gradle
    [proguard.cfg]
2017-03-29 Fix sensorConnect and put in temp fix for startSensor

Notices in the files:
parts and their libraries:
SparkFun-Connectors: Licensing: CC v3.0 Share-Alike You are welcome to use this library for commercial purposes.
